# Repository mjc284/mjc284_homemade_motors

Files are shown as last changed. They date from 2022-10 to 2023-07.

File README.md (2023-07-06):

# mjc284_repurposing_stators
Building homemade AC and DC motors by repurposing old stators and rotors.

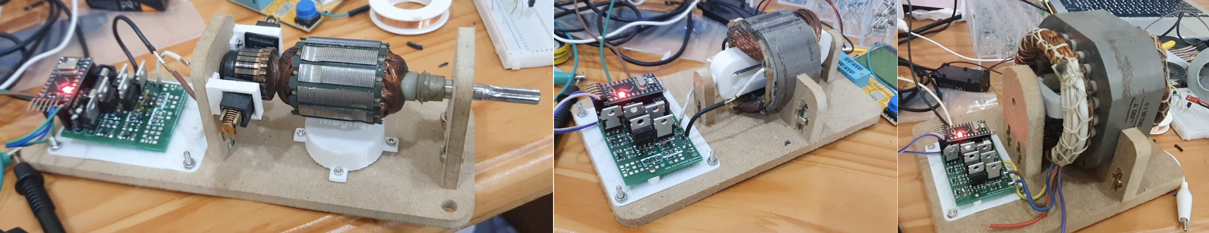
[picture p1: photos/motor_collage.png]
Collage


### Video demonstration:
https://www.youtube.com/watch?v=uW4sdqWzGSA

### Objective:
This project consists of three motors made of a repurposed drill motor rotor, a drill motor stator, and a fan motor stator respectively. All the repurposed parts were salvaged from broken electronics. 

The drill rotor was driven by providing PWM pulses through an H-bridge and through the slip ring, with a strong permanent magnet under the rotor to provide the magnetic field. 

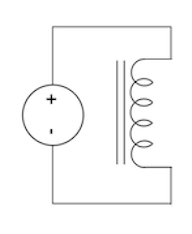
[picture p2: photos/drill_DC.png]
Drill_DC Drill DC


The drill motor stator was driven as a 2-pole AC motor by alternating the current through the coils with an H-bridge. Although this type of motor is not practical without a starting coil, the setup still managed to demonstrate that the rotor would turn half of the time clockwise and the other half counter-clockwise.

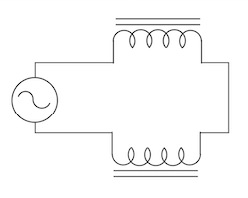
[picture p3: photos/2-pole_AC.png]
2-Pole_AC 2-Pole AC


The fan stator was that of an 8-pole AC motor. However, there were three output wires consisting of two for each coil phases and one for common. Therefore, all three legs of the inverter used and the coil excitation sequence was programmed.

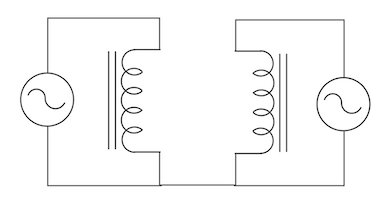
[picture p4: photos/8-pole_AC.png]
8-Pole_AC 8-Pole AC


Custom rotors were made for the 2-pole and 8-pole AC motor, which contains permanent magnets of opposite fields on each arms of the rotor.

### Project Workflow:
- All the hardware and circuit were modelled using Fusion 360.
- Some of the parts were machined from 11mm MDF using a desktop-CNC. 
- Some of the parts were 3D-printed with postprocessing from Ultimaker-Cura.
- PCB was manufactured from the Fusion 360 gerber file by commercial PCB services.
- Arduino-pro mini was programmed and used to drive the circuit.

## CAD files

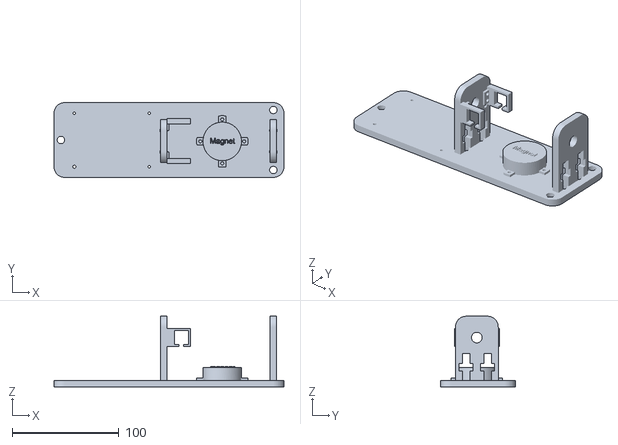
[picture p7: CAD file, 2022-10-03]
project_files/hardware/drill_DC/assembly v3.stl
215.0 x 70.0 x 66.0

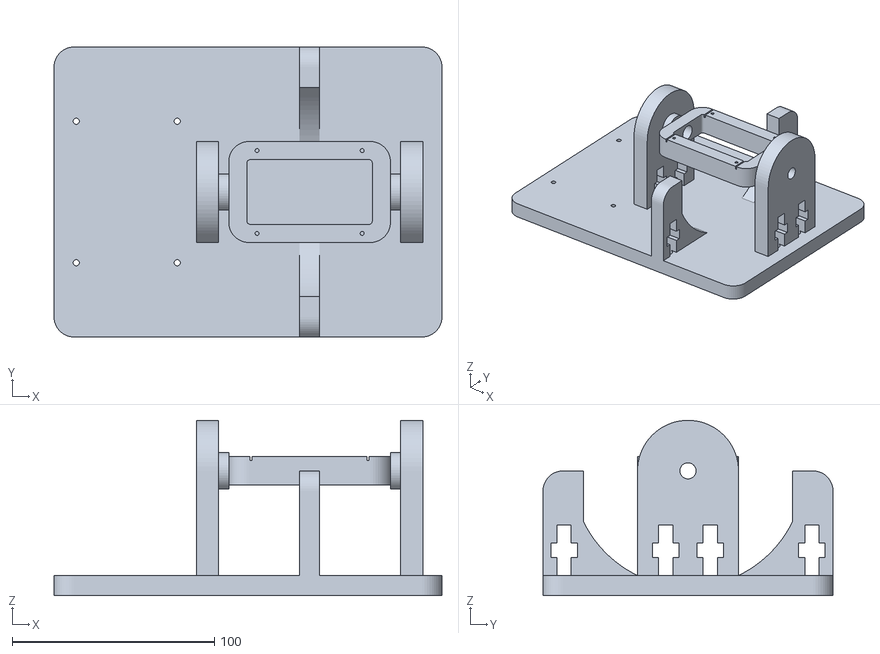
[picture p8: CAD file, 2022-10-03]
project_files/hardware/8-pole_AC/assembly v5.stl
192.0 x 143.6 x 86.8

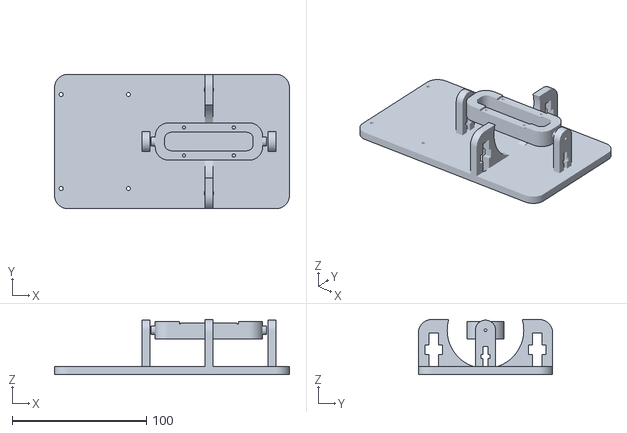
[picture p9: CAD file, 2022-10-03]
project_files/hardware/2-pole_AC/assembly v3.stl
175.0 x 100.0 x 41.0

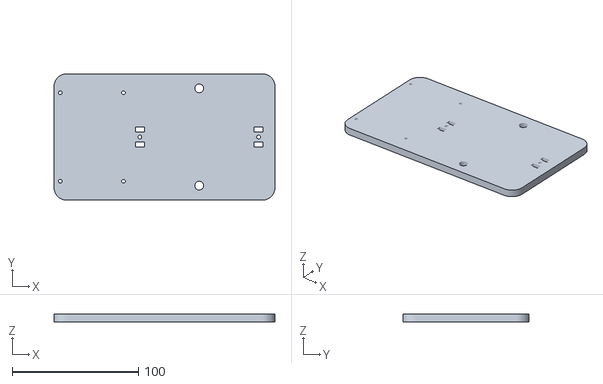
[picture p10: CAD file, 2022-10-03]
project_files/hardware/2-pole_AC/base v4.stl
175.0 x 100.0 x 6.00

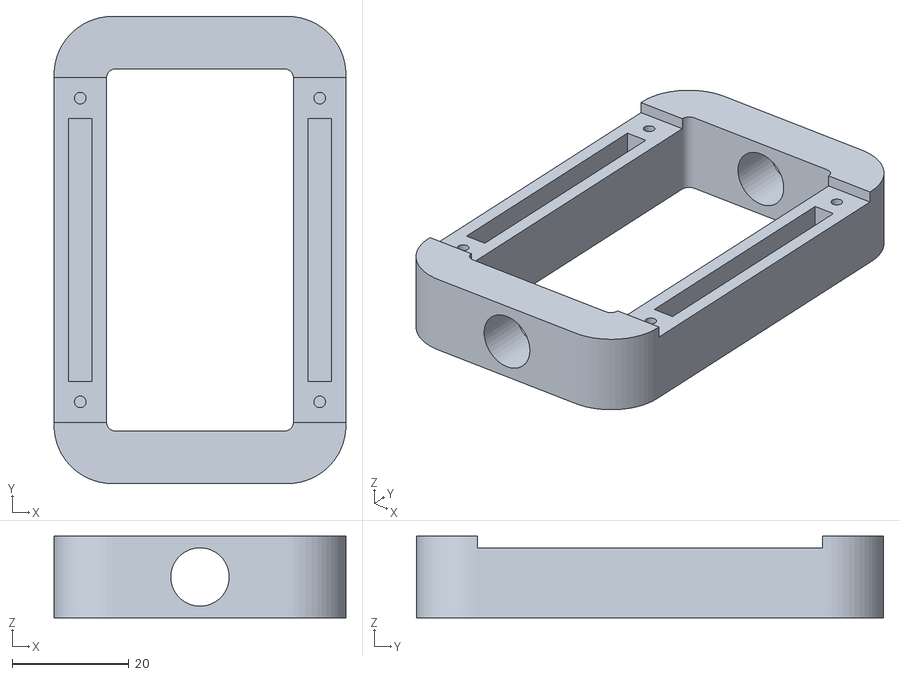
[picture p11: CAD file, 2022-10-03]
project_files/hardware/8-pole_AC/rotor v2.stl
50.0 x 80.0 x 14.0

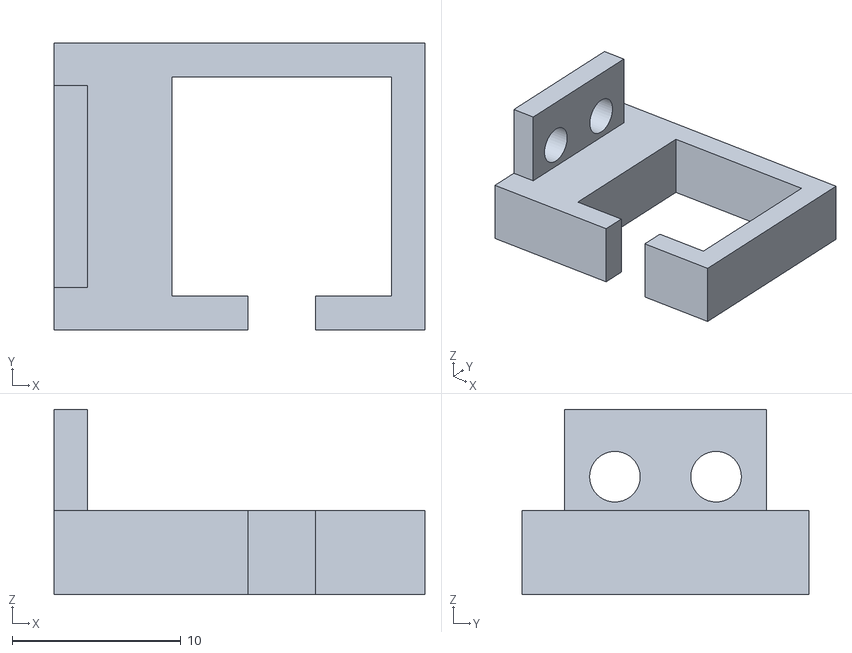
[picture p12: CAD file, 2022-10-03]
project_files/hardware/drill_DC/holder_R v6.stl
22.0 x 17.0 x 11.0

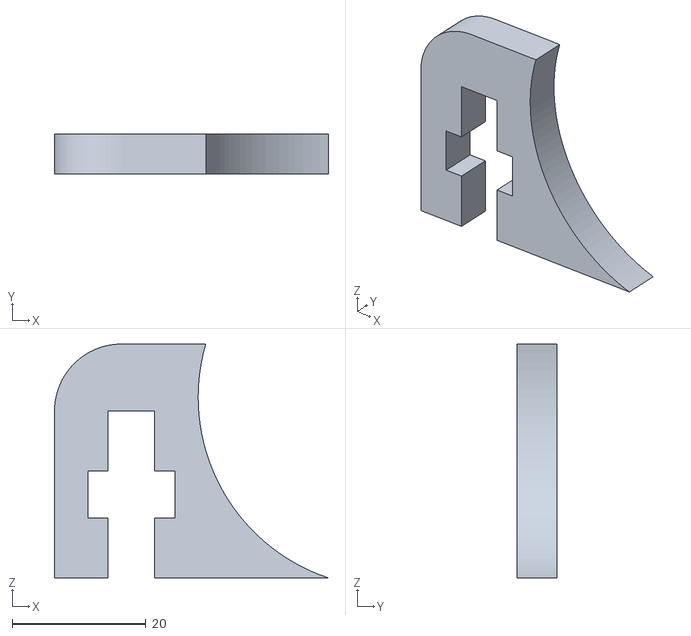
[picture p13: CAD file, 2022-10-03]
project_files/hardware/2-pole_AC/stator_mount v4.stl
41.0 x 6.00 x 35.0

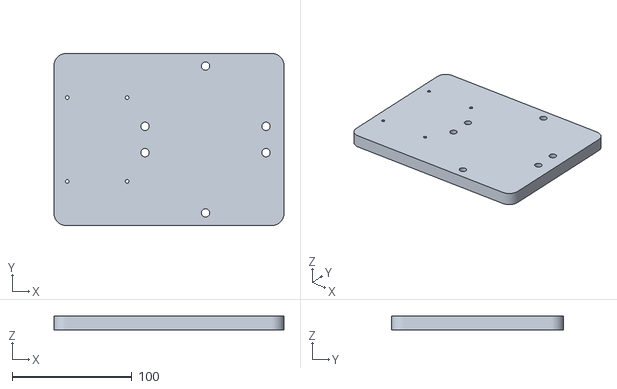
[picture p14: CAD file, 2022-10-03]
project_files/hardware/8-pole_AC/base v6.stl
192.0 x 143.6 x 12.0

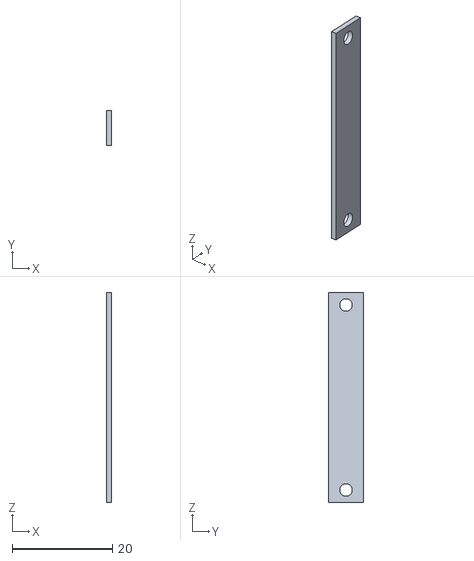
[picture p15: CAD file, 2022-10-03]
project_files/hardware/2-pole_AC/rotor_2_cap v3.stl
1.00 x 7.00 x 42.0

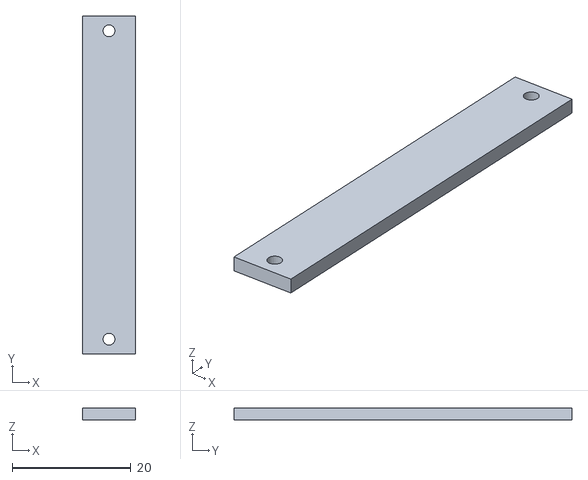
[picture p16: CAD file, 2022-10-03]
project_files/hardware/8-pole_AC/rotor_cap v3.stl
9.00 x 57.0 x 2.00

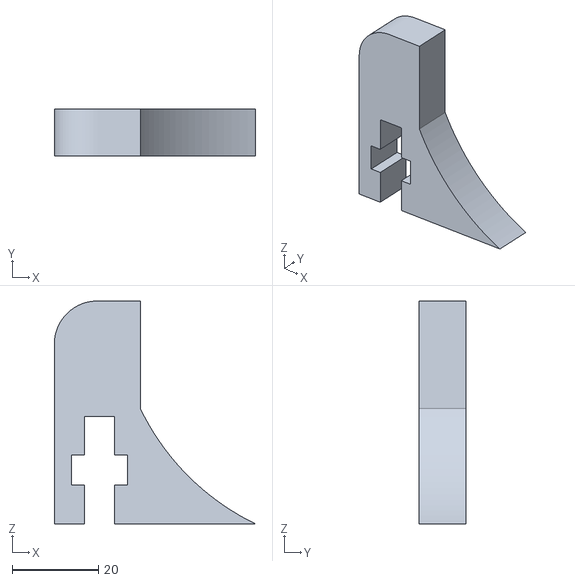
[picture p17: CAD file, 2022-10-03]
project_files/hardware/8-pole_AC/stator_stand v4.stl
46.8 x 11.0 x 51.8

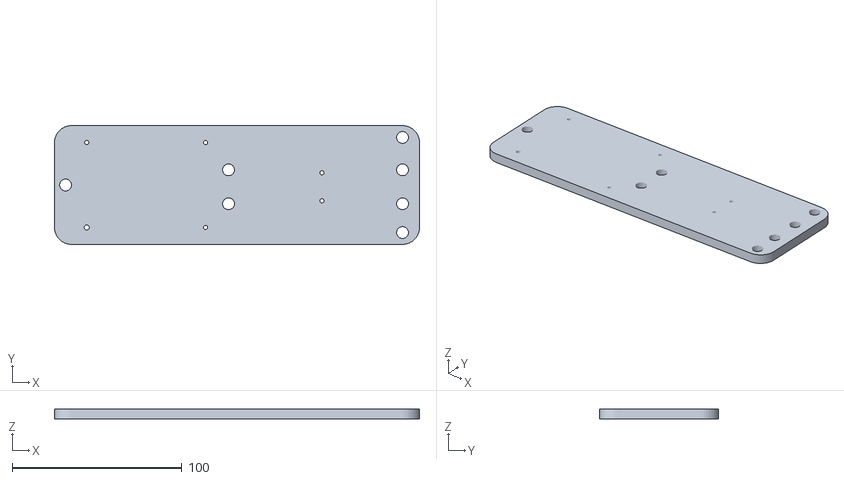
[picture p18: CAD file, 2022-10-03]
project_files/hardware/drill_DC/base v8.stl
215.0 x 70.0 x 6.00

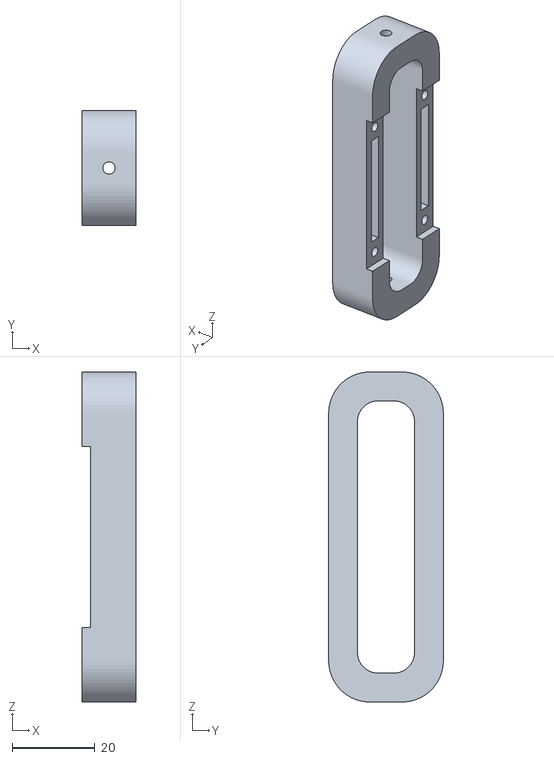
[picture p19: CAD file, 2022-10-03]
project_files/hardware/2-pole_AC/rotor_2 v4.stl
13.0 x 27.8 x 80.0

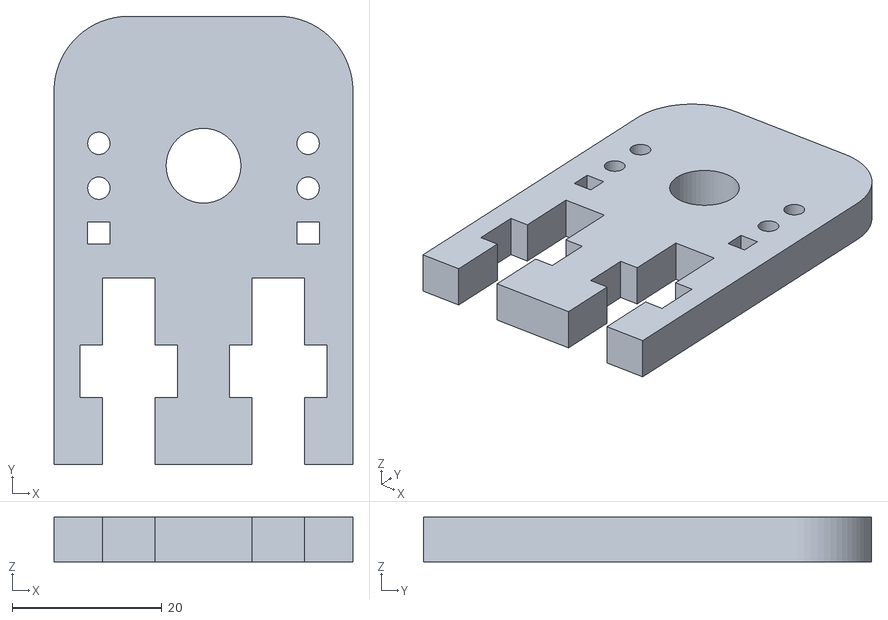
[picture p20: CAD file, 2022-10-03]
project_files/hardware/drill_DC/stand_L v10.stl
40.0 x 60.0 x 6.00

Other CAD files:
project_files/hardware/drill_DC/holder_L v3.stl
project_files/hardware/2-pole_AC/rotor_mount v3.stl
project_files/hardware/drill_DC/stand_R v3.stl
project_files/hardware/8-pole_AC/rotor_stand v6.stl
project_files/hardware/2-pole_AC/assembly v3.f3z
project_files/hardware/2-pole_AC/base v4.f3d
project_files/hardware/2-pole_AC/rotor_2 v4.f3d
project_files/hardware/2-pole_AC/rotor_2_cap v3.f3d
project_files/hardware/2-pole_AC/rotor_mount v3.f3d
project_files/hardware/2-pole_AC/stator_mount v4.f3d
project_files/hardware/2-pole_AC/washer v1.f3d
project_files/hardware/2-pole_AC/washer v1.stl
project_files/hardware/8-pole_AC/assembly v5.f3z
project_files/hardware/8-pole_AC/base v6.f3d
project_files/hardware/8-pole_AC/rotor v2.f3d
project_files/hardware/8-pole_AC/rotor_cap v3.f3d
project_files/hardware/8-pole_AC/rotor_stand v6.f3d
project_files/hardware/8-pole_AC/stator_stand v4.f3d
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

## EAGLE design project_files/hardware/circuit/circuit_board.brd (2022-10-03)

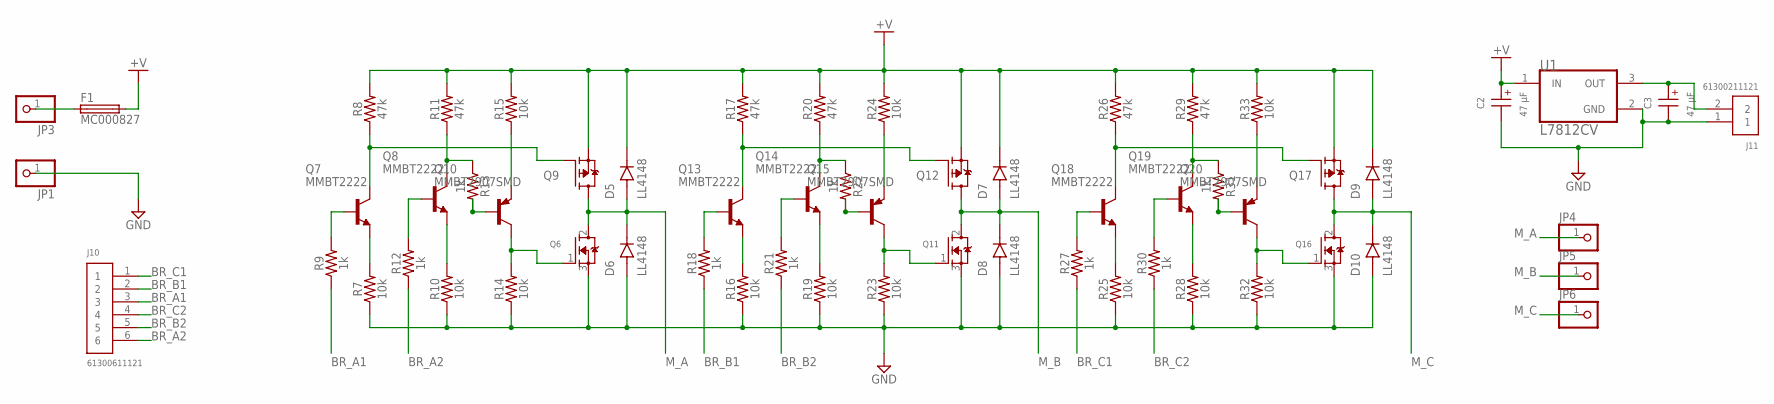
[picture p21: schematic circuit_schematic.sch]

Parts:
C2, C3: 47 µF; WCAP-ATET_5X11(DXL)
D5, D6, D7, D8, D9, D10: LL4148; DIO_LL4148
F1: MC000827
J10: 61300611121
J11: 61300211121
JP1, JP3, JP4, JP5, JP6: PINHD-1X1; 1X01
Q6, Q11, Q16: MOSFET-NGDS_TO220V; TO220V
Q7, Q8, Q13, Q14, Q18, Q19: MMBT2222; SOT23-BEC
Q9, Q12, Q17: MOSFET-PGDS_TO220V; TO220V
Q10, Q15, Q20: MMBT2907SMD; SOT23-BEC
R7, R10, R14, R15, R16, R19, R23, R24, R25, R28, R32, R33: 10k; 1206
R8, R11, R17, R20, R26, R29: 47k; 1206
R9, R12, R13, R18, R21, R22, R27, R30, R31: 1k; 1206
U1: L7812CV; TO-220-3

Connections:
+V: C2.1 (+), D5.C, D7.C, D9.C, F1.P$2 (2), Q9.3 (S), Q12.3 (S), Q17.3 (S), R8.2, R11.2, R15.2, R17.2, R20.2, R24.2, R26.2, R29.2, R33.2, U1.1 (IN)
BR_A1: J10.3, R9.1
BR_A2: J10.6, R12.1
BR_B1: J10.2, R18.1
BR_B2: J10.5, R21.1
BR_C1: J10.1, R27.1
BR_C2: J10.4, R30.1
GND: C2.2 (-), C3.2 (-), D6.A, D8.A, D10.A, J11.1, JP1.1, Q6.3 (S), Q11.3 (S), Q16.3 (S), R7.1, R10.1, R14.1, R16.1, R19.1, R23.1, R25.1, R28.1, R32.1, U1.2 (GND)
M_A: D5.A, D6.C, JP4.1, Q6.2 (D), Q9.2 (D)
M_B: D7.A, D8.C, JP5.1, Q11.2 (D), Q12.2 (D)
M_C: D9.A, D10.C, JP6.1, Q16.2 (D), Q17.2 (D)
unnamed: Q8.C, R11.1, R13.1
unnamed: Q8.B, R12.2
unnamed: Q8.E, R10.2
unnamed: Q6.1 (G), Q10.C, R14.2
unnamed: Q10.E, R15.1
unnamed: Q7.B, R9.2
unnamed: Q7.C, Q9.1 (G), R8.1
unnamed: Q7.E, R7.2
unnamed: Q10.B, R13.2
unnamed: F1.P$1 (1), JP3.1
unnamed: Q14.C, R20.1, R22.1
unnamed: Q14.B, R21.2
unnamed: Q14.E, R19.2
unnamed: Q11.1 (G), Q15.C, R23.2
unnamed: Q15.E, R24.1
unnamed: Q13.B, R18.2
unnamed: Q12.1 (G), Q13.C, R17.1
unnamed: Q13.E, R16.2
unnamed: C3.1 (+), J11.2, U1.3 (OUT)
unnamed: Q15.B, R22.2
unnamed: Q19.C, R29.1, R31.1
unnamed: Q19.B, R30.2
unnamed: Q19.E, R28.2
unnamed: Q16.1 (G), Q20.C, R32.2
unnamed: Q20.E, R33.1
unnamed: Q18.B, R27.2
unnamed: Q17.1 (G), Q18.C, R26.1
unnamed: Q18.E, R25.2
unnamed: Q20.B, R31.2

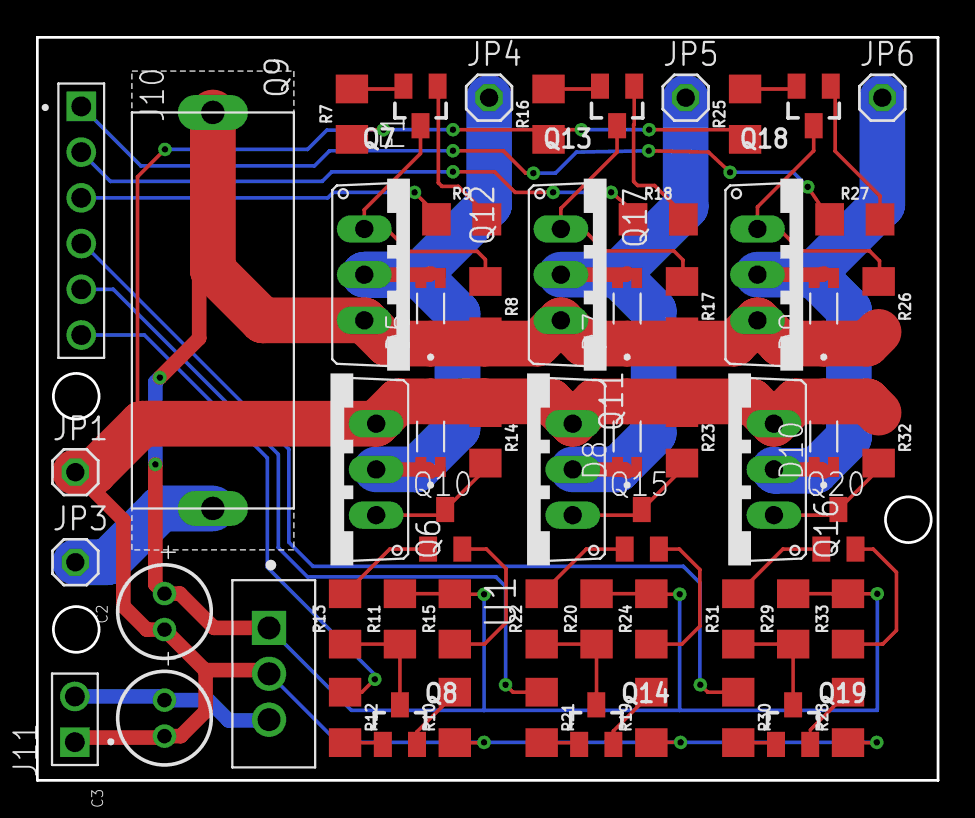
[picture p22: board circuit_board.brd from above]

Board: 2 copper layers, 50.0 x 41.3 mm, 59 parts (0 on the bottom side), 40 nets.

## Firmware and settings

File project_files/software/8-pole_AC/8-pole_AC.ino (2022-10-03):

int motor_AU = 9;
int motor_BU = 8;
int motor_CU = 7;
int motor_AD = 6;
int motor_BD = 5;
int motor_CD = 4;

void drive(float mode, int cycles)
{
  int cnt = 0;
  if(mode == 0)
  {
    while(cnt < cycles)
    {
      digitalWrite(motor_AU, LOW);
      digitalWrite(motor_BU, LOW);
      digitalWrite(motor_CU, LOW);
      digitalWrite(motor_AD, LOW);
      digitalWrite(motor_BD, LOW);
      digitalWrite(motor_CD, LOW);
      delay(3);
      digitalWrite(motor_AU, LOW);
      digitalWrite(motor_BU, LOW);
      digitalWrite(motor_CU, LOW);
      digitalWrite(motor_AD, LOW);
      digitalWrite(motor_BD, LOW);
      digitalWrite(motor_CD, LOW);
      delay(1);
      cnt++;
    }
  }
  else if(mode == 1)
  {
    while(cnt < cycles)
    {
      digitalWrite(motor_AU, HIGH);
      digitalWrite(motor_BU, LOW);
      digitalWrite(motor_CU, LOW);
      digitalWrite(motor_AD, LOW);
      digitalWrite(motor_BD, HIGH);
      digitalWrite(motor_CD, LOW);
      delay(3);
      digitalWrite(motor_AU, LOW);
      digitalWrite(motor_BU, LOW);
      digitalWrite(motor_CU, LOW);
      digitalWrite(motor_AD, LOW);
      digitalWrite(motor_BD, LOW);
      digitalWrite(motor_CD, LOW);
      delay(1);
      cnt++;
    }
  }
  else if(mode == 1.5)
  {
    while(cnt < cycles)
    {
      digitalWrite(motor_AU, HIGH);
      digitalWrite(motor_BU, LOW);
      digitalWrite(motor_CU, HIGH);
      digitalWrite(motor_AD, LOW);
      digitalWrite(motor_BD, HIGH);
      digitalWrite(motor_CD, LOW);
      delay(2);
      digitalWrite(motor_AU, LOW);
      digitalWrite(motor_BU, LOW);
      digitalWrite(motor_CU, LOW);
      digitalWrite(motor_AD, LOW);
      digitalWrite(motor_BD, LOW);
      digitalWrite(motor_CD, LOW);
      delay(2);
      cnt++;
    }
  }
  else if(mode == -1)
  {
    while(cnt < cycles)
    {
      digitalWrite(motor_AU, LOW);
      digitalWrite(motor_BU, HIGH);
      digitalWrite(motor_CU, LOW);
      digitalWrite(motor_AD, HIGH);
      digitalWrite(motor_BD, LOW);
      digitalWrite(motor_CD, LOW);
      delay(3);
      digitalWrite(motor_AU, LOW);
      digitalWrite(motor_BU, LOW);
      digitalWrite(motor_CU, LOW);
      digitalWrite(motor_AD, LOW);
      digitalWrite(motor_BD, LOW);
      digitalWrite(motor_CD, LOW);
      delay(1);
      cnt++;
    }
  }
  else if(mode == -1.5)
  {
    while(cnt < cycles)
    {
      digitalWrite(motor_AU, LOW);
      digitalWrite(motor_BU, HIGH);
      digitalWrite(motor_CU, LOW);
      digitalWrite(motor_AD, HIGH);
      digitalWrite(motor_BD, LOW);
      digitalWrite(motor_CD, HIGH);
      delay(2);
      digitalWrite(motor_AU, LOW);
      digitalWrite(motor_BU, LOW);
      digitalWrite(motor_CU, LOW);
      digitalWrite(motor_AD, LOW);
      digitalWrite(motor_BD, LOW);
      digitalWrite(motor_CD, LOW);
      delay(2);
      cnt++;
    }
  }
  else if(mode == 2)
  {
    while(cnt < cycles)
    {
      digitalWrite(motor_AU, LOW);
      digitalWrite(motor_BU, LOW);
      digitalWrite(motor_CU, HIGH);
      digitalWrite(motor_AD, LOW);
      digitalWrite(motor_BD, HIGH);
      digitalWrite(motor_CD, LOW);
      delay(3);
      digitalWrite(motor_AU, LOW);
      digitalWrite(motor_BU, LOW);
      digitalWrite(motor_CU, LOW);
      digitalWrite(motor_AD, LOW);
      digitalWrite(motor_BD, LOW);
      digitalWrite(motor_CD, LOW);
      delay(1);
      cnt++;
    }
  }
  else if(mode == 2.5)
  {
    while(cnt < cycles)
    {
      digitalWrite(motor_AU, LOW);
      digitalWrite(motor_BU, LOW);
      digitalWrite(motor_CU, HIGH);
      digitalWrite(motor_AD, HIGH);
      digitalWrite(motor_BD, LOW);
      digitalWrite(motor_CD, LOW);
      delay(4);
      cnt++;
    }
  }
  else if(mode == -2)
  {
    while(cnt < cycles)
    {
      digitalWrite(motor_AU, LOW);
      digitalWrite(motor_BU, HIGH);
      digitalWrite(motor_CU, LOW);
      digitalWrite(motor_AD, LOW);
      digitalWrite(motor_BD, LOW);
      digitalWrite(motor_CD, HIGH);
      delay(3);
      digitalWrite(motor_AU, LOW);
      digitalWrite(motor_BU, LOW);
      digitalWrite(motor_CU, LOW);
      digitalWrite(motor_AD, LOW);
      digitalWrite(motor_BD, LOW);
      digitalWrite(motor_CD, LOW);
      delay(1);
      cnt++;
    }
  }
  else if(mode == -2.5)
  {
    while(cnt < cycles)
    {
      digitalWrite(motor_AU, HIGH);
      digitalWrite(motor_BU, LOW);
      digitalWrite(motor_CU, LOW);
      digitalWrite(motor_AD, LOW);
      digitalWrite(motor_BD, LOW);
      digitalWrite(motor_CD, HIGH);
      delay(4);
      cnt++;
    }
  }
}

void setup() {
  // put your setup code here, to run once:
  pinMode(motor_AU, OUTPUT);
  pinMode(motor_BU, OUTPUT);
  pinMode(motor_CU, OUTPUT);
  pinMode(motor_AD, OUTPUT);
  pinMode(motor_BD, OUTPUT);
  pinMode(motor_CD, OUTPUT);
  drive(0, 2);
}

float x = 100;
float sequence[8] = {1, 1.5, 2, 2.5, -1, -1.5, -2, -2.5};
int index = 0;

void loop() {
  //Turn clockwise slowly.
  for(int i = 0; i < 16; i++)
  {
    drive(sequence[index], 200);
    index++;
    if(index > 7){index = 0;}
  }
  
  //Turn clockwise faster.
  for(int i = 0; i < 50; i++)
  {
    drive(sequence[index], 8);
    index++;
    if(index > 7){index = 0;}
  }
  
  //Turn clockwise fast.
  for(int i = 0; i < 2000; i++)
  {
    drive(sequence[index], 2);
    index++;
    if(index > 7){index = 0;}
  }
  
  //Rest
  drive(0, 800);

  //Turn counter-clockwise slowly.
  for(int i = 0; i < 16; i++)
  {
    drive(sequence[index], 200);
    index--;
    if(index < 0){index = 7;}
  }

  //Turn counter-clockwise faster.
  for(int i = 0; i < 50; i++)
  {
    drive(sequence[index], 8);
    index--;
    if(index < 0){index = 7;}
  }

  //Turn counter-clockwise fast.
  for(int i = 0; i < 2000; i++)
  {
    drive(sequence[index], 2);
    index--;
    if(index < 0){index = 7;}
  }

  //Rest
  drive(0, 800);
}

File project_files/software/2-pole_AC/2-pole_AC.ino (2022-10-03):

int motor_RU = 8;
int motor_LU = 7;
int motor_RD = 5;
int motor_LD = 4;

void drive(int mode, int cycles)
{
  int cnt = 0;
  if(mode == 0)
  {
    while(cnt < cycles)
    {
      digitalWrite(motor_RU, LOW);
      digitalWrite(motor_LU, LOW);
      digitalWrite(motor_RD, LOW);
      digitalWrite(motor_LD, LOW);
      delay(3);
      digitalWrite(motor_RU, LOW);
      digitalWrite(motor_LU, LOW);
      digitalWrite(motor_RD, LOW);
      digitalWrite(motor_LD, LOW);
      delay(1);
      cnt++;
    }
  }
  else if(mode == 1)
  {
    while(cnt < cycles)
    {
      digitalWrite(motor_RU, LOW);
      digitalWrite(motor_LU, HIGH);
      digitalWrite(motor_RD, HIGH);
      digitalWrite(motor_LD, LOW);
      delay(3);
      digitalWrite(motor_RU, LOW);
      digitalWrite(motor_LU, LOW);
      digitalWrite(motor_RD, LOW);
      digitalWrite(motor_LD, LOW);
      delay(1);
      cnt++;
    }
  }
  else if(mode == -1)
  {
    while(cnt < cycles)
    {
      digitalWrite(motor_RU, HIGH);
      digitalWrite(motor_LU, LOW);
      digitalWrite(motor_RD, LOW);
      digitalWrite(motor_LD, HIGH);
      delay(3);
      digitalWrite(motor_RU, LOW);
      digitalWrite(motor_LU, LOW);
      digitalWrite(motor_RD, LOW);
      digitalWrite(motor_LD, LOW);
      delay(1);
      cnt++;
    }
  }
}

void setup() {
  // put your setup code here, to run once:
  pinMode(motor_RU, OUTPUT);
  pinMode(motor_LU, OUTPUT);
  pinMode(motor_RD, OUTPUT);
  pinMode(motor_LD, OUTPUT);
  drive(0, 2);
}

void loop() {
  //Alternate poles slowly.
  for(int i = 0; i < 4; i++)
  {
    drive(1, 17);
    drive(0, 350);
    drive(-1, 17);
    drive(0, 350);
  }

  //Alternate poles quickly, driving the rotor.
  for(int i = 0; i < 150; i++)
  {
    drive(1, 13);
    drive(0, 1);
    drive(-1, 13);
    drive(0, 1);
  }
}

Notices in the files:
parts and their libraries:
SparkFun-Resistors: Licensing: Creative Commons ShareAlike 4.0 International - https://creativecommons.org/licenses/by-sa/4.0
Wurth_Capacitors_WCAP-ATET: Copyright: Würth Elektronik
